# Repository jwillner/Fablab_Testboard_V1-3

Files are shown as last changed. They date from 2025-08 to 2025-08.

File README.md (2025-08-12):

<!-- Fablab-Winti ESP32-C6-Dev-Projekt – README.md -->
<!-- Einfach als "README.md" im Repository speichern -->

# Fablab-Winti KiCad-ESP32-C6-Projekt  
> **Work-in-progress** – du  layoutest, du lötest, du programmierst  Slack `#fablab-winti`
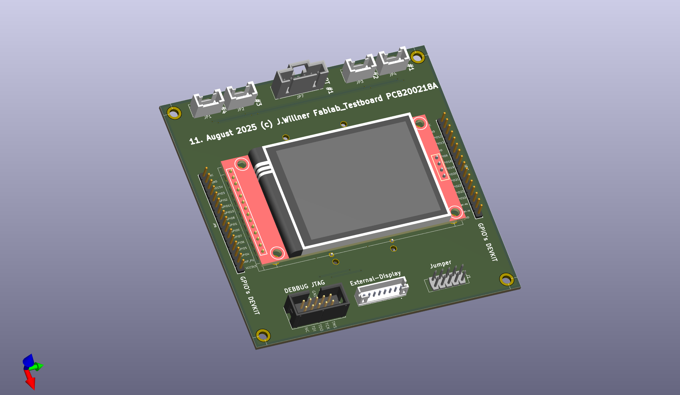
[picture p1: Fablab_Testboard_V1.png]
Fablab_Testboard

## 🧰 Hardware-Baukasten (Stand: August 2025)

| Teil | Beschreibung | Kurz-Link |
|---|---|---|
| **ESP32-C6-Zero** (Waveshare) | USB-C, RISC-V, Wi-Fi 6, BLE, Zigbee | [Wiki](https://www.waveshare.com/wiki/ESP32-C6-Zero) |
| **ESP32-C6-Dev-Kit-N8** | Pin-kompatibel, 8 MB Flash | [Wiki](https://www.waveshare.com/wiki/ESP32-C6-DEV-KIT-N8) |
| **1,69" TFT 240×280 ST7789** | SPI, 3,3 V, abgerundete Ecken | [AZ-Delivery](https://www.az-delivery.de/products/1-69-zoll-tft-display) |
| **2,4" TFT Touch ILI9341** | Größer + Touch, selbe Lib | [AZ-Delivery](https://www.az-delivery.de/products/2-4-tft-lcd-touch-display-1) |
| **SIM7080G** | LTE Cat-M & NB-IoT + GNSS | [SIMCom](https://www.simcom.com/product/SIM7080G.html) |

---

## 📂 KiCad-Projekt öffnen

```bash
git clone https://github.com/jwillner/Fablab_Testboard_V1-3.git
cd Fablab_Testboard_V1-3
kicad Fablab_Testboard_V1-3.kicad_pro   # Schema + PCB + 3D sofort sichtbar

#Beispiel Software-Projekte
| Repo                                                                       | Funktion                                    | Status                 |
| -------------------------------------------------------------------------- | ------------------------------------------- | ---------------------- |
| [**ESP32-C6-HelloWorld**](https://github.com/jwillner/ESP32-C6-HelloWorld) | LED blinkt, UART loggt → Erststart-Template | ✅ lauffähig            |
| [**ESP32-C6-UART0**](https://github.com/jwillner/ESP32-C6-UART0)           | Bidirektionale UART-Bridge + Echo-Test      | 🔄 Review gesucht      |
| [**ESP32-C6-TFT191-V1**](https://github.com/jwillner/ESP32-C6-TFT191-V1)   | 1,69" TFT Grundgrafik (ST7789)              | 🔄 Optimierung offen   |
| [**ESP32-C6-TFT191-V2**](https://github.com/jwillner/ESP32-C6-TFT191-V2)   | 1,69" TFT + Touch + SD-Card                 | 🚧 Work-in-Progress    |
| **BME280-C6** *(coming)*                                                   | Temperatur / Luftfeuchte / Druck per MQTT   | 🔍 Mitstreiter gesucht |
| **ICM-20948-C6** *(coming)*                                                | 9-DoF IMU → Lage-/Bewegungs-Logger          | 🔍 Mitstreiter gesucht |
| **SIM7080G-C6-GNSS** *(coming)*                                            | LTE-M Upload + GNSS-Tracking                | 🔍 Mitstreiter gesucht |

Du willst mithelfen? Einfach im jeweiligen Repo ein Issue aufmachen oder direkt einen Branch pushen!
🎤 Feedback & Mitmachen
Slack: #fablab-winti
Issues: wenn’s qualmt, Ticket aufmachen
PRs: wenn’s läuft, teilen
Lizenz
Hardware CERN-OHL-S v2 • Software MIT

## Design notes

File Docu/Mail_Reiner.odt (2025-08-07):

Reiner Ulrich | Di., 29. Juli, 22:28 (vor 21 Stunden) | | an mich; buergisser.pascal

Hallo Joachim, hallo Pascal,

@Joachim: das 2.4-TFT-Modul sieht ja schon gut aus!!!!

Ich habe Euch unter https://e.pcloud.link/publink/ (https://e.pcloud.link/publink/show?code=kZ4TyKZ9cM0rxJLgxj36K7uMsBeFX4OFr8V)

noch weitere Verzeichnisse bereitgestellt:

Arduino_IDE_CodeBeispiel - das ist der Code der auf dem CO2-Messgerät läuft, das ich mitgebracht hatte. Kann man mit der Arduino IDE kompilieren. Nicht hübsch. Das meiste hatte ich mit ChatGPT-Hilfe zusammengebastelt, Quick and dirty. Ich habe noch eine viel schönere Version für 3.5"-Display, aber das sind ca. 5000 Zeilen Code... damit befassen wir uns später.

Ich hatte dort ein 1.54" - Display verwendet, das 2.4" das ich Euch mitgegeben habe, sollte den gleichen ST7789 Controller haben, also eigentlich 1:1 lauffähig sein ! Im Code die Auflösung anpassen, also z.B. hier:

#define TFT_WIDTH 240
#define TFT_HEIGHT 240

das 2.4" hat 320x240 Auflösung

im Script sieht man die Verwendung der Pins für das TFT Modul und den I2C:

// Define custom SDA and SCL pins for SCD40 (I2C communication)
#define SDA_PIN 8 // Version 1 & 2: GPIO8
#define SCL_PIN 2 // Version 1: GPIO9, Version 2: GPIO 2

// ILI7789 SPI pins
#define TFT_CS 6 // SPI CS aka _CS_
#define TFT_CLK 20 // SPI Clock pin aka _SCL_
#define TFT_MOSI 7 // SPI MOSI pin _SDA_
#define TFT_RST 21 // TFT Reset aka _RST_
#define TFT_DC 5 // TFT Data/Command selection aka _DC_
#define BACKLIGHT_PIN 10 // Backlight control pin ka _BL_

// Switches
#define SW12PIN 3
#define SW3PIN 9 // on V1 board it is GPIO2, on V2 board it will be GPIO9

#define LEDRed 0
#define LEDGreen 1

#define LDR 4

Wenn wir bei einer einfacheren Lösung die LED und die Taster weglassen, dann werden die Pins 3,9,0,1,4 am ESP32 frei und die brauchen wir auch, um z.B. das Touch-Modul im Display anzuschliessen, siehe unten

Alternativ kann man in einer weiteren Version der Platine einen ESP32-S3 verwenden, der hat mehr verfügbare Pins, dann kann man auch die Taster, LED und das Touch-Modul ansprechen...

MiniCO2_V2 - das Kicad Projekt für die Musterplatine

Das ist die "Maximal-Lösung" des Übungsprojekts, aber für Euer Projekt sehe ich eine einfachere Lösung, z.B. nur ESP32, das Display, 1 Sensor. Keine Taster, kein RTC Modul. Ihr könnt an diesem Projekt herumspielen oder - als Lerneffekt viel besser - es als Vorlage verwenden und versuchen, es in reduzierter Version komplett neu nachzubauen !

Die Pins des 2.4" TFT sind glaub anders angeordnet und leicht anders (besser) beschriftet, aber ansonsten sind die verwenden Pins 1:1 zum 1.54 modul - ähnliches TFT Display mit SPI-Bus, technisch alles gleich ausser der Auflösung.

Das 2.4" hat noch die Touchfunktion, die ist auf den Zusätzlichen Pins T_CLK, T_CS, T_DIN, T_DO, T_IRQ auf dem Modul herausgeführt. Das ist ebenfalls ein SPI-Bus. Wenn man diese Touch-Funktionen auch am ESP32 anschliessen will, kann man sie einfach mit dem SPI-Bus des TFT-Teils zusammenhängen, z.B. wie folgt:

T_CLK > SCK > ESP32 GPIO20

T_DIN > SDI(MOSI) > ESP32 GPIO7

T_DO > ESP32 neuer Pin, z.B. GPIO9 wenn wir die Taster weglassen

T_IRQ > brauchen wir nicht zwingend, können wir auch unverdrahtet lassen. Im Code kann man auch einfach jede 1/50 Sekunde mal abfragen, ob das TFT einen Touch registriert hat und wo der ist und dann auf diesen reagieren

T_CS > das ist der Chip-Select des Touch moduls. Das müssen wir auf einen eigenen Pin führen, z.b. GPIO3, wenn wir die Taster weglassen. Damit wird unterschieden, ob der SPI-Bus das TFT ansprechen will (GPIO6 aktivieren) oder das Touch-Modul ansprechen will (GPIO3 setzen). Das müsste im Code natürlich noch eingebaut werden...

Das TFT-Modul bleibt im übrigen wie oben verdrahtet:

CS > GPIO6
RESET > GPIO21
DC > GPIO5
LED (Backlight) > GPIO10

GND > GND

VCC > 5V (das Modul hat einen eigenen Spannungwandler und darf und soll daher an 5V angeschlossen werden) Sollte man nochmal prüfen, ob das wirklich stimmt für dieses Modul !!!

Fusion360_Gehäuse

Hier habe ich einen Fusion360 export hinkopiert mit dem Gehäuse. Das müsste deutlich angepasst werden für das 2.4"-Display... um das Schnittbild abzuschalten bei "Analyse" die Sichtbarkeit (Auge) klicken, dann ist es nicht mehr aufgeschnitten. Es besteht aus 3 Teilen: Front, Rückwand und den Distanzhalter. Sehr mühsam zum zusammenlöten, deshalb eine etwas lockerere 2.4"-Version... wäre besser.

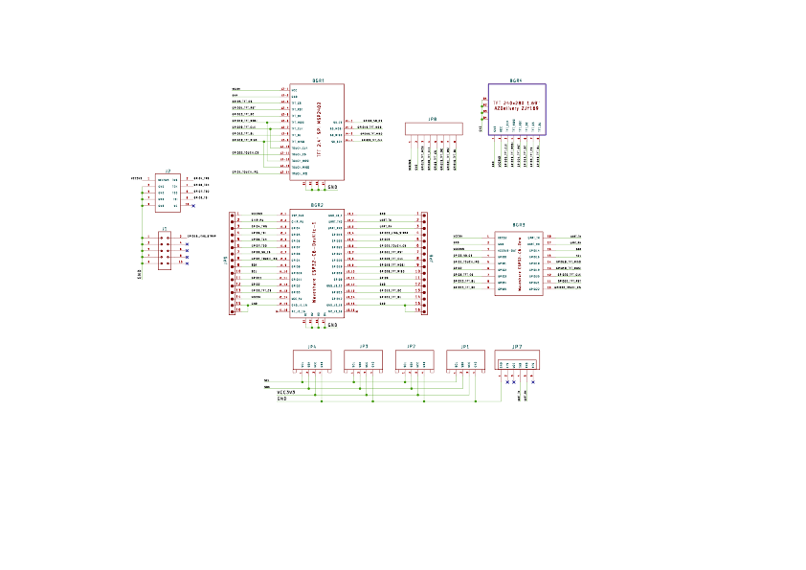
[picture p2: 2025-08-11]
Docu/Schema.png

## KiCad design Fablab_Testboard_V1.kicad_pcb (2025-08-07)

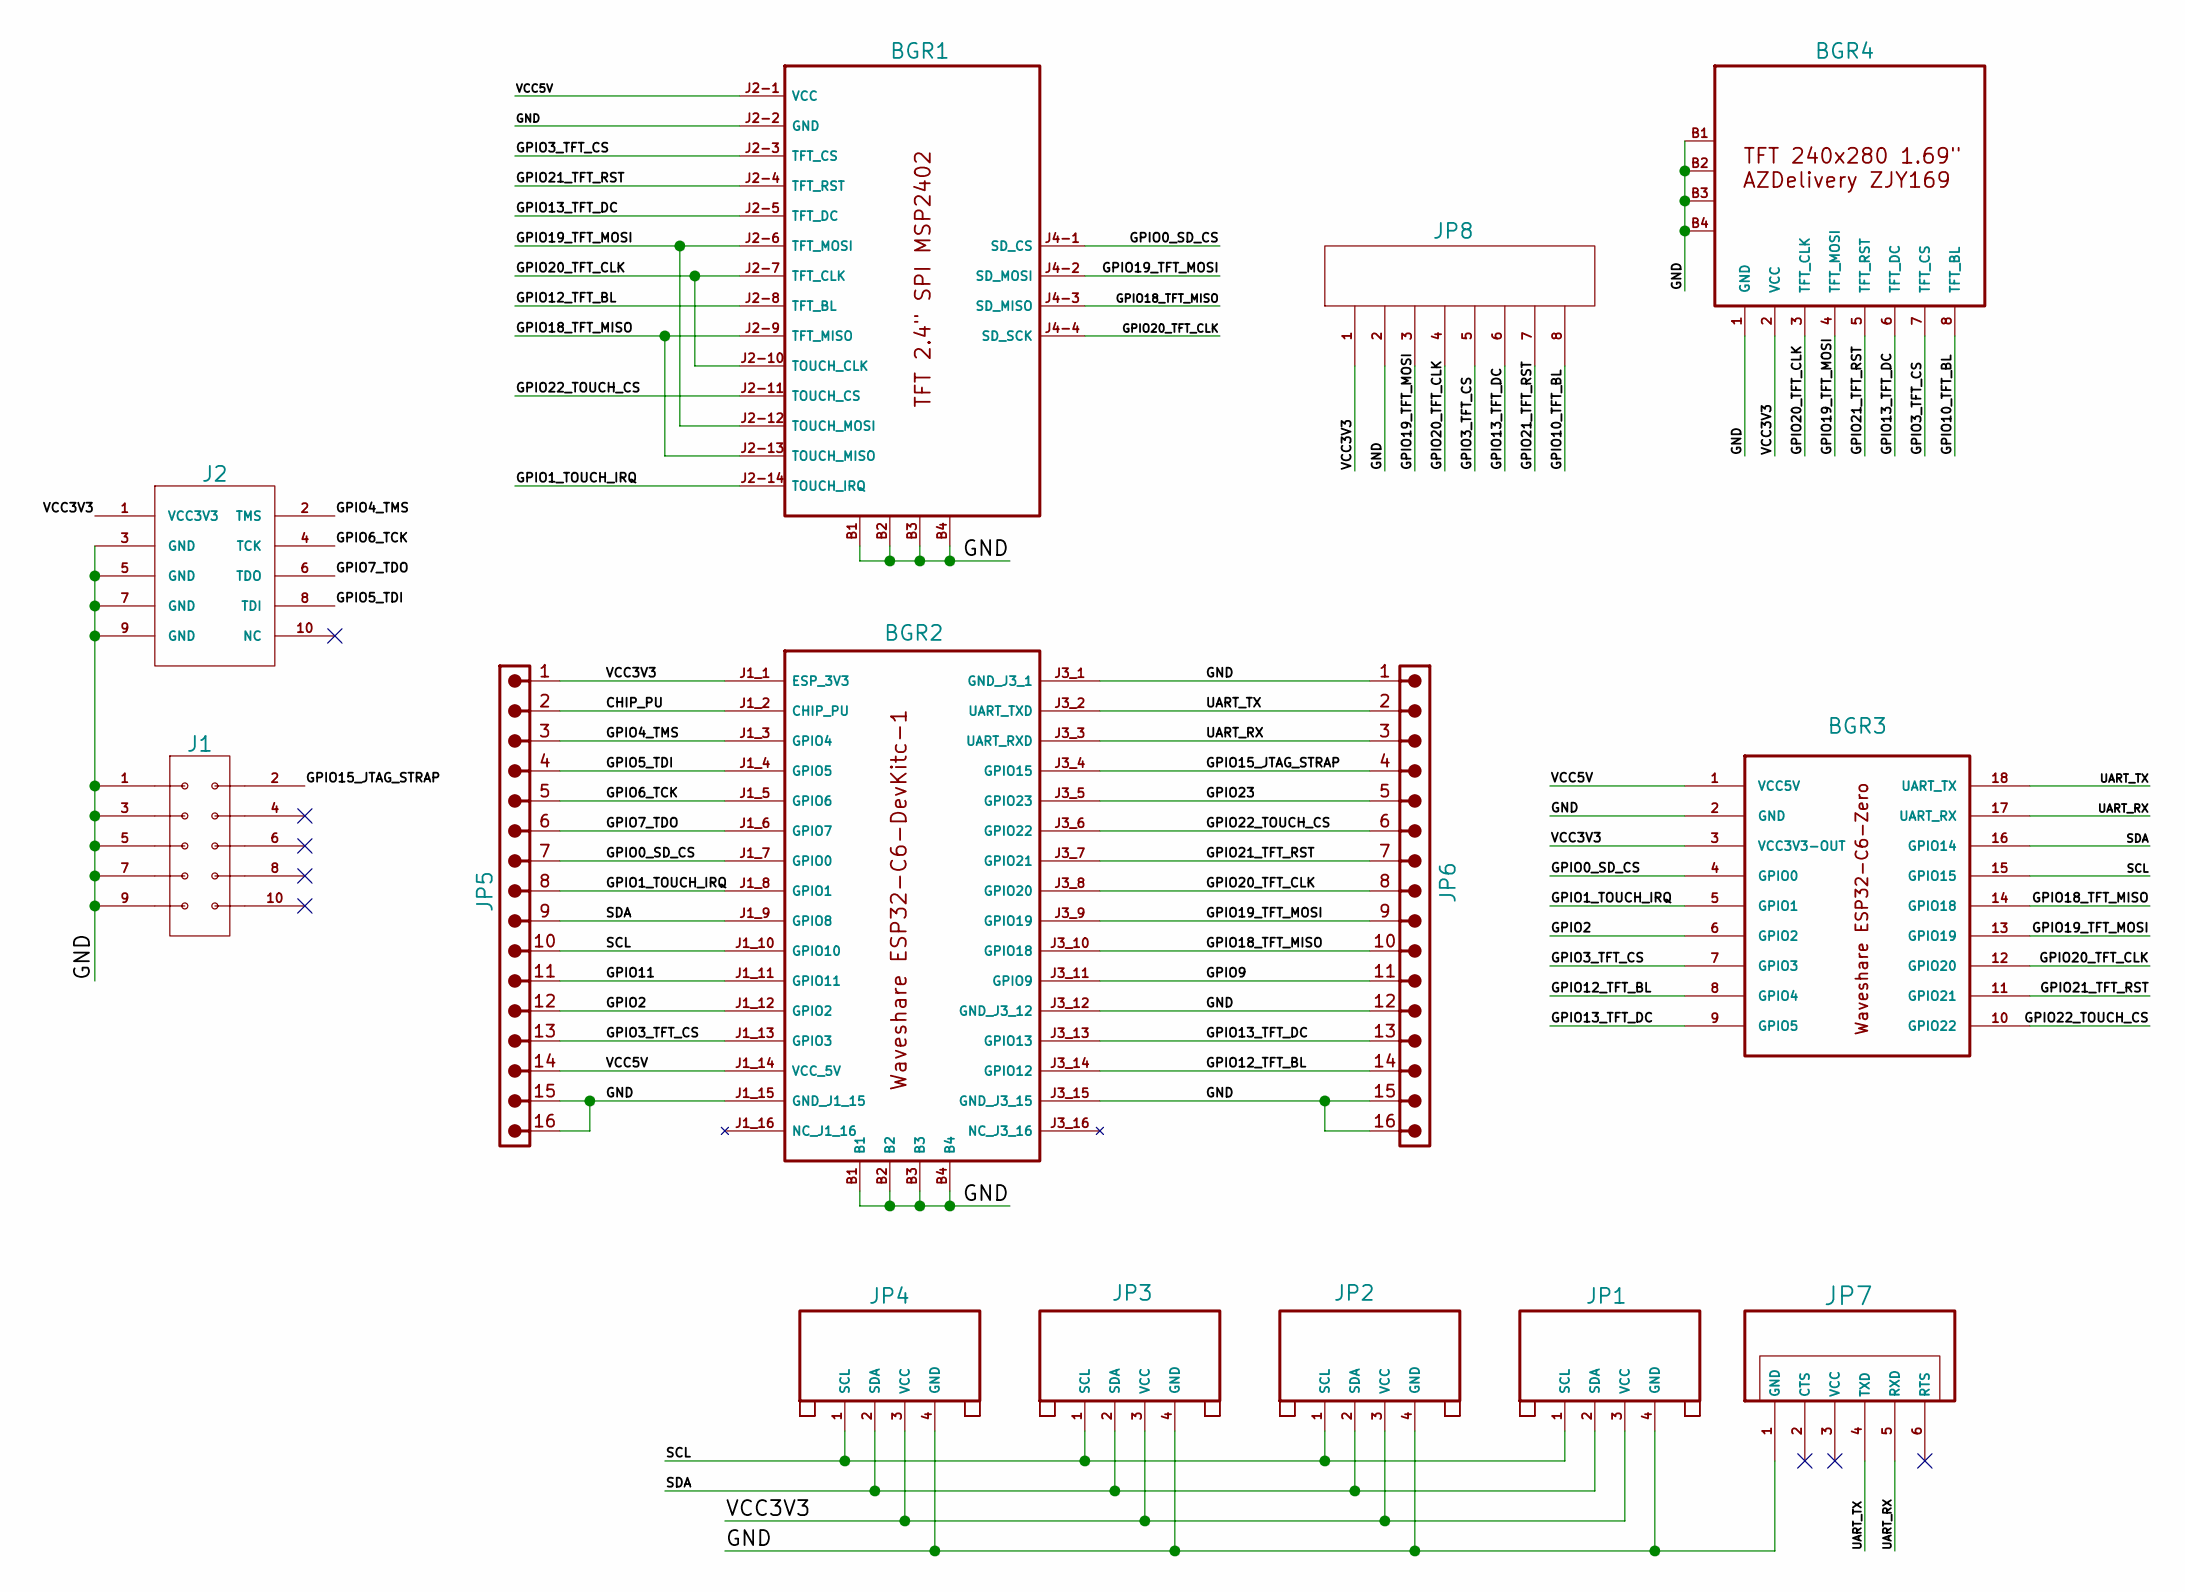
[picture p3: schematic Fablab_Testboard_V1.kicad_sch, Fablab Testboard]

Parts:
BGR1: 2.4inch_SPI_Module_ILI9341_SKU_MSP2402
BGR2: MODULE_ESP32-C6-DEVKITC-1-N8
BGR3: WS-ESP32-C3-ZERO; WS_ESP32-C3_ZERO
BGR4: AZDELIVERY-ZJY169; ZJY169-AZDELIVERY
J1: MOLEX-901310765; PARTREV J
J2: SBH11-PBPC-D05-ST-BK; SULLINS_SBH11-PBPC-D05-ST-BK; PARTREV J
JP1, JP2, JP3, JP4: SEEED_110990030
JP5, JP6: WUERTH_61301611121; WUERTH-61301611121
JP7: Molex-705430040; Molex-0705430040
JP8: B10B-PH-K-S_LF__SN_; JST_B8B-PH-K-S; PARTREV JP

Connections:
/CHIP_PU: BGR2.J1_2 (CHIP_PU), JP5.2
/GND: BGR1.B1, BGR1.B2, BGR1.B3, BGR1.B4, BGR1.J2-2 (GND), BGR2.B1, BGR2.B2, BGR2.B3, BGR2.B4, BGR2.J1_15 (GND_J1_15), BGR2.J3_1 (GND_J3_1), BGR2.J3_12 (GND_J3_12), BGR2.J3_15 (GND_J3_15), BGR3.2 (GND), BGR4.1 (GND), BGR4.B1, BGR4.B2, BGR4.B3, BGR4.B4, J1.1, J1.3, J1.5, J1.7, J1.9, J2.3 (GND), J2.5 (GND), J2.7 (GND), J2.9 (GND), JP1.4 (GND), JP2.4 (GND), JP3.4 (GND), JP4.4 (GND), JP5.15, JP5.16, JP6.1, JP6.12, JP6.15, JP6.16, JP7.1 (GND), JP8.2
/GPIO0_SD_CS: BGR1.J4-1 (SD_CS), BGR2.J1_7 (GPIO0), BGR3.4 (GPIO0), JP5.7
/GPIO1_TOUCH_IRQ: BGR1.J2-14 (TOUCH_IRQ), BGR2.J1_8 (GPIO1), BGR3.5 (GPIO1), JP5.8
/GPIO2: BGR2.J1_12 (GPIO2), BGR3.6 (GPIO2), JP5.12
/GPIO3_TFT_CS: BGR1.J2-3 (TFT_CS), BGR2.J1_13 (GPIO3), BGR3.7 (GPIO3), BGR4.7 (TFT_CS), JP5.13, JP8.5
/GPIO4_TMS: BGR2.J1_3 (GPIO4), J2.2 (TMS), JP5.3
/GPIO5_TDI: BGR2.J1_4 (GPIO5), J2.8 (TDI), JP5.4
/GPIO6_TCK: BGR2.J1_5 (GPIO6), J2.4 (TCK), JP5.5
/GPIO7_TDO: BGR2.J1_6 (GPIO7), J2.6 (TDO), JP5.6
/GPIO9: BGR2.J3_11 (GPIO9), JP6.11
/GPIO10_TFT_BL: BGR4.8 (TFT_BL), JP8.8
/GPIO11: BGR2.J1_11 (GPIO11), JP5.11
/GPIO12_TFT_BL: BGR1.J2-8 (TFT_BL), BGR2.J3_14 (GPIO12), BGR3.8 (GPIO4), JP6.14
/GPIO13_TFT_DC: BGR1.J2-5 (TFT_DC), BGR2.J3_13 (GPIO13), BGR3.9 (GPIO5), BGR4.6 (TFT_DC), JP6.13, JP8.6
/GPIO15_JTAG_STRAP: BGR2.J3_4 (GPIO15), J1.2, JP6.4
/GPIO18_TFT_MISO: BGR1.J2-9 (TFT_MISO), BGR1.J2-13 (TOUCH_MISO), BGR1.J4-3 (SD_MISO), BGR2.J3_10 (GPIO18), BGR3.14 (GPIO18), JP6.10
/GPIO19_TFT_MOSI: BGR1.J2-6 (TFT_MOSI), BGR1.J2-12 (TOUCH_MOSI), BGR1.J4-2 (SD_MOSI), BGR2.J3_9 (GPIO19), BGR3.13 (GPIO19), BGR4.4 (TFT_MOSI), JP6.9, JP8.3
/GPIO20_TFT_CLK: BGR1.J2-7 (TFT_CLK), BGR1.J2-10 (TOUCH_CLK), BGR1.J4-4 (SD_SCK), BGR2.J3_8 (GPIO20), BGR3.12 (GPIO20), BGR4.3 (TFT_CLK), JP6.8, JP8.4
/GPIO21_TFT_RST: BGR1.J2-4 (TFT_RST), BGR2.J3_7 (GPIO21), BGR3.11 (GPIO21), BGR4.5 (TFT_RST), JP6.7, JP8.7
/GPIO22_TOUCH_CS: BGR1.J2-11 (TOUCH_CS), BGR2.J3_6 (GPIO22), BGR3.10 (GPIO22), JP6.6
/GPIO23: BGR2.J3_5 (GPIO23), JP6.5
/SCL: BGR2.J1_10 (GPIO10), BGR3.15 (GPIO15), JP1.1 (SCL), JP2.1 (SCL), JP3.1 (SCL), JP4.1 (SCL), JP5.10
/SDA: BGR2.J1_9 (GPIO8), BGR3.16 (GPIO14), JP1.2 (SDA), JP2.2 (SDA), JP3.2 (SDA), JP4.2 (SDA), JP5.9
/UART_RX: BGR2.J3_3 (UART_RXD), BGR3.17 (UART_RX), JP6.3, JP7.5 (RXD)
/UART_TX: BGR2.J3_2 (UART_TXD), BGR3.18 (UART_TX), JP6.2, JP7.4 (TXD)
/VCC3V3: BGR2.J1_1 (ESP_3V3), BGR3.3 (VCC3V3-OUT), BGR4.2 (VCC), J2.1 (VCC3V3), JP1.3 (VCC), JP2.3 (VCC), JP3.3 (VCC), JP4.3 (VCC), JP5.1, JP8.1
/VCC5V: BGR1.J2-1 (VCC), BGR2.J1_14 (VCC_5V), BGR3.1 (VCC5V), JP5.14

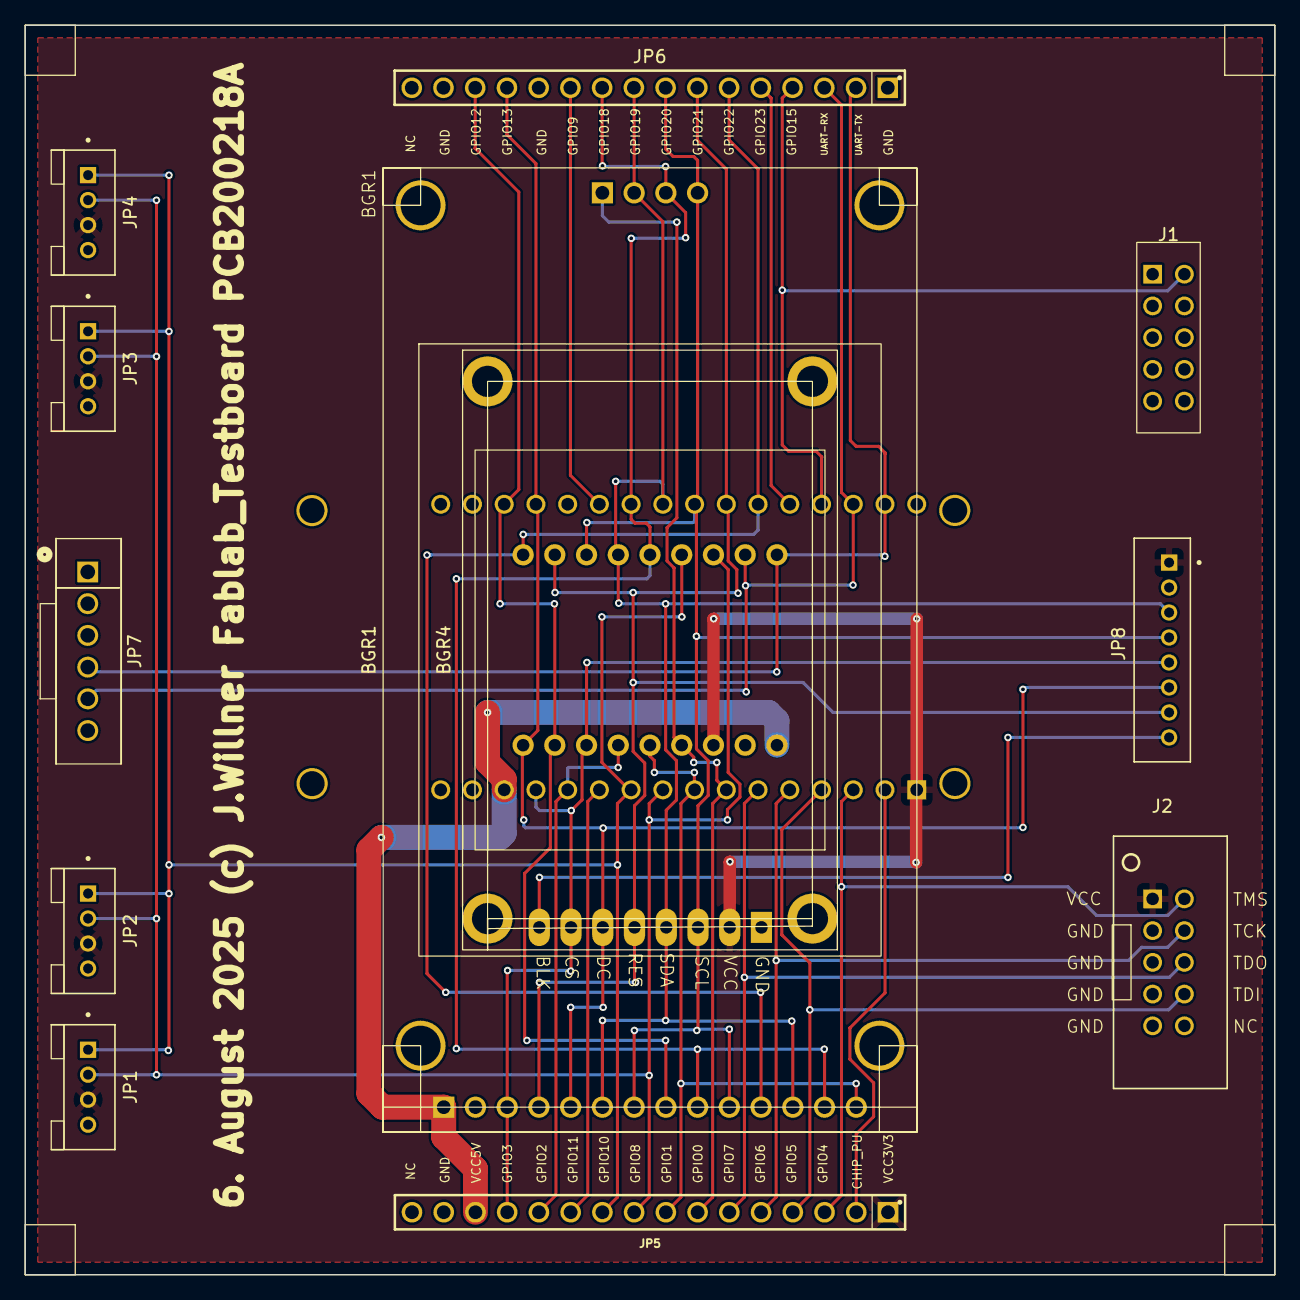
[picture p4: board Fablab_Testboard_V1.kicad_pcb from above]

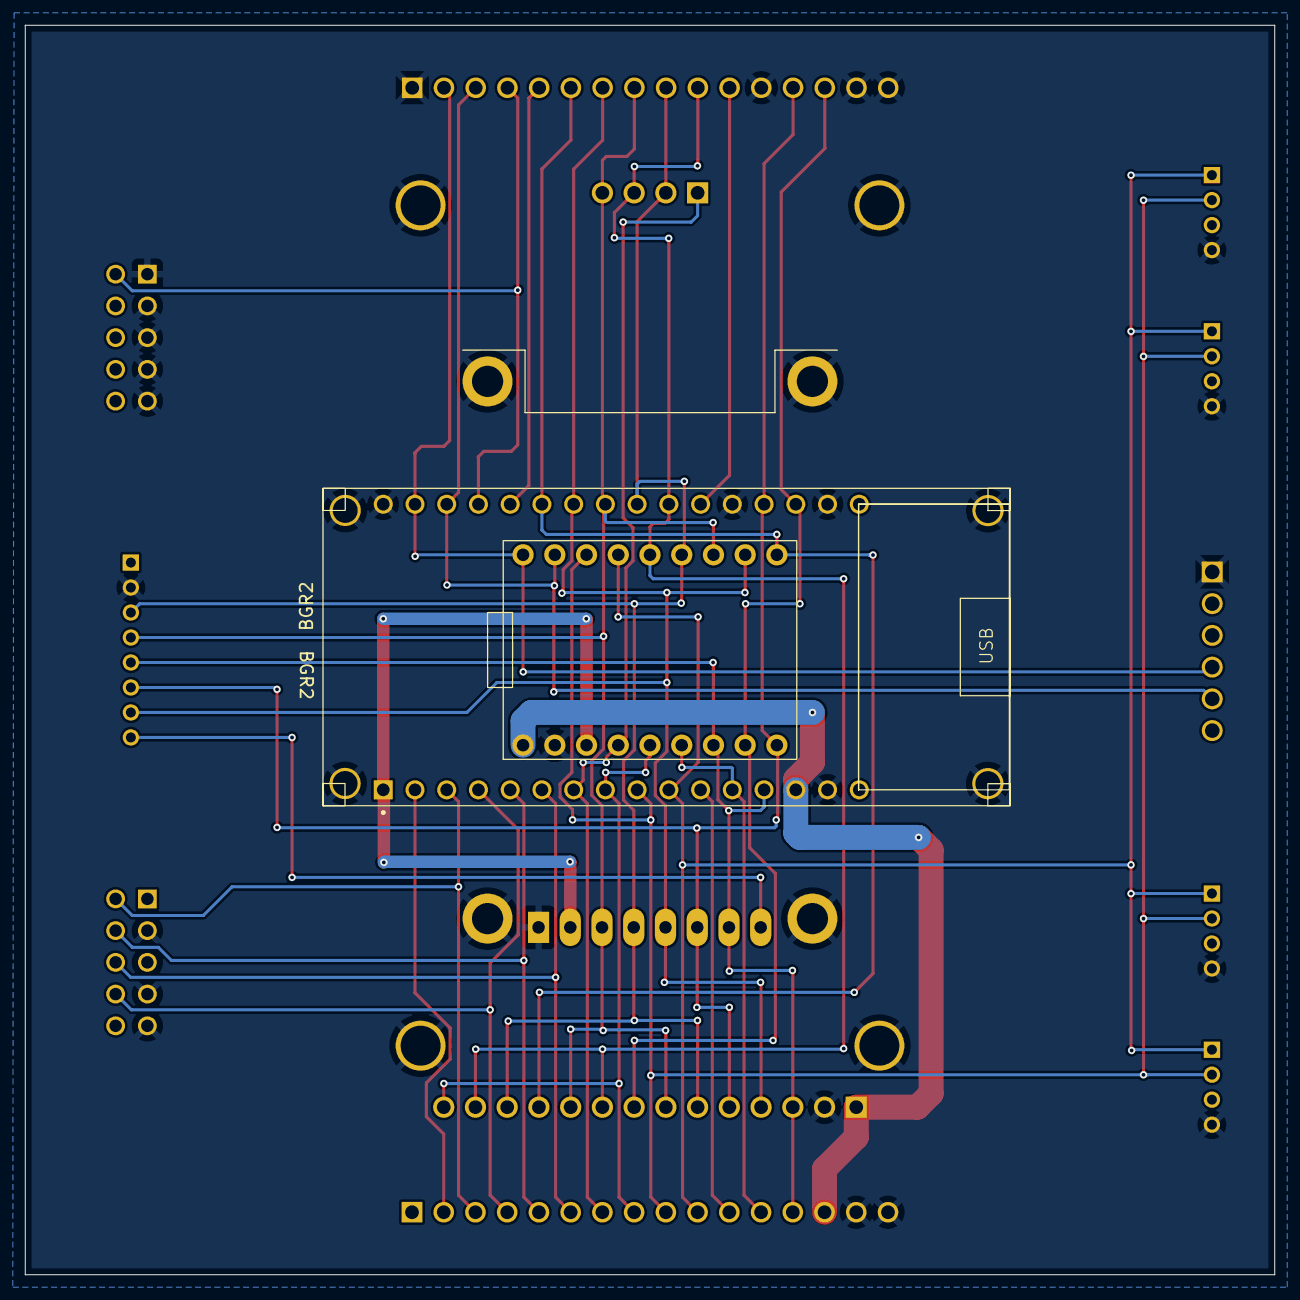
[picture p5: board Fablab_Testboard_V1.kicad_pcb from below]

Board: 2 copper layers, 100.0 x 100.0 mm, 14 parts (2 on the bottom side), 28 nets.

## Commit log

2025-08-07 Initial commit of Fablab Testboard V1.3
    [Fablab_Testboard_V1.kicad_pcb, Fablab_Testboard_V1.kicad_sch, freerouting.dsn]
2025-08-11 zusätzliche Bilder und Silkscreen, plus Bohrlöcher
